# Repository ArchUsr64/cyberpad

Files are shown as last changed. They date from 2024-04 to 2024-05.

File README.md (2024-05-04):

# cyberpad
Macropad in cyberpunk style

## Features
- 16-key matrix layout
- Two rotary encoders (knobs)
- RGB lighting

## Parts Required
| Part | Quantity | Description |
|  - | - |  -  |
| Raspberry Pi Pico | 1 | Microcontroller that powers the whole thing |
| M3 screw | 8 | Used to mount the top and bottom plates together |
| M2 screw | 4 | Used to mount the raspberry pi pico to the top plate |
| M3 standoff | 4 | Provide spacing between the top and bottom plate to house the electronics |
| Switch | 16 | Key switches mounted to the top plate (both 3-pin and 5-pin work)|
| Keycaps | 16 | Keycaps for the switches |
| Diodes | 16 | Required to achieve n-key rollover |
| USB Cable | 1 | Used to connect the pico to the computer |
| RGB LED | 6 | For RGB lighting, firmware expects common anode type |
| Potentiometer | 3 | Used to control the color of RGB lights |
| Type C breakout board (optional) | 1 | Use TP2 and TP3 test points for external USB port |
| Bump Switch (optional) | 1 | Used to get the board to bootloader mode |

## Wiring



The diodes should be connected in `Column to Row` ordering i.e the `cathode` of the diode (the side with the line) should be facing away from the keys and the `cathode` of the diodes in same row should all be connected.  

The `anode` of the diodes should each connect to one pin of the switch and the other pin should be connected straight with all the pins of switches in same column. 
For wiring the Raspberry Pi Pico, the indexing used in the wiring diagram above corresponds to the pico's pinout as follows:

| Row | 0 | 1 | 2 | 3 |
|  -  | - | - | - | - |
| Pin | 5 | 6 | 7 | 8 |

| Column | 0 | 1 | 2 | 3 |
|  -  | - | - | - | - |
| Pin | 20 | 19 | 21 | 22 |

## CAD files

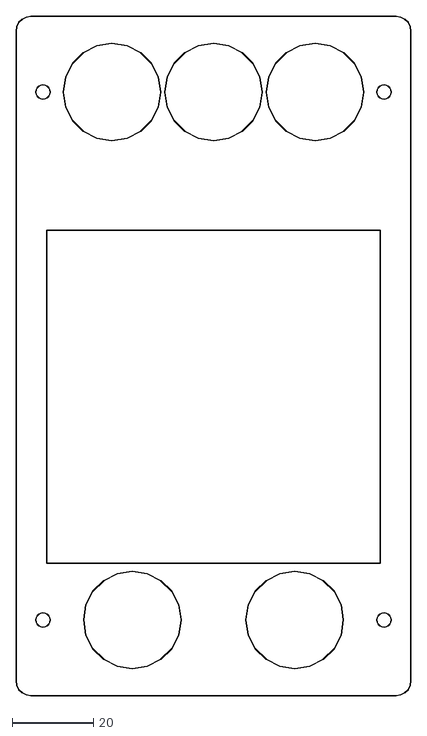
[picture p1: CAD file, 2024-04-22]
cad_files/top_cover.dxf
97.2 x 167.2

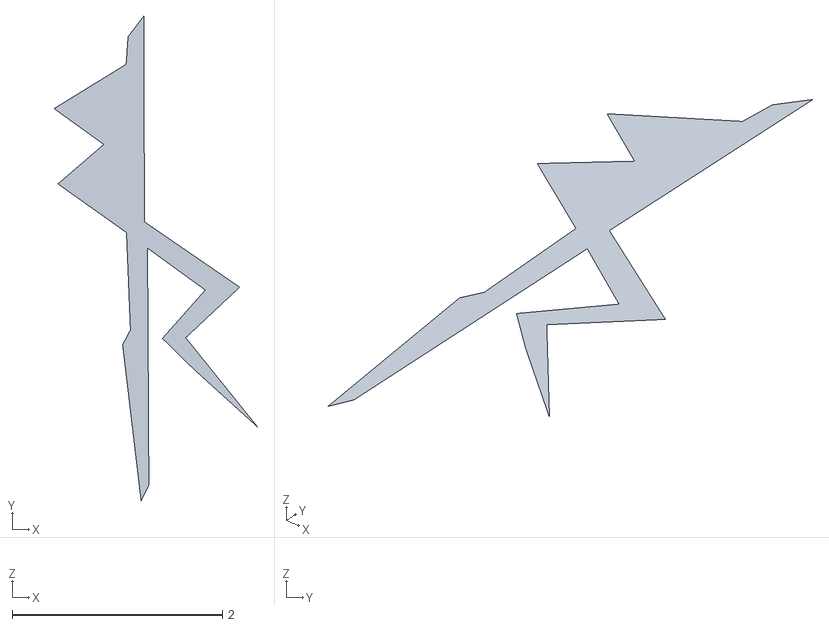
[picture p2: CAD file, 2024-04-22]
edge.stl
1.94 x 4.62 x 0

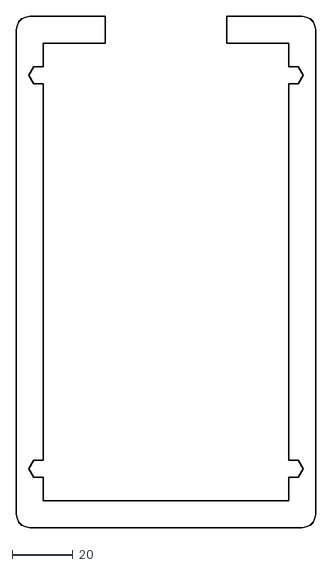
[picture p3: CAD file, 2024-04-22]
cad_files/middle_bottom.dxf
98.8 x 168.8

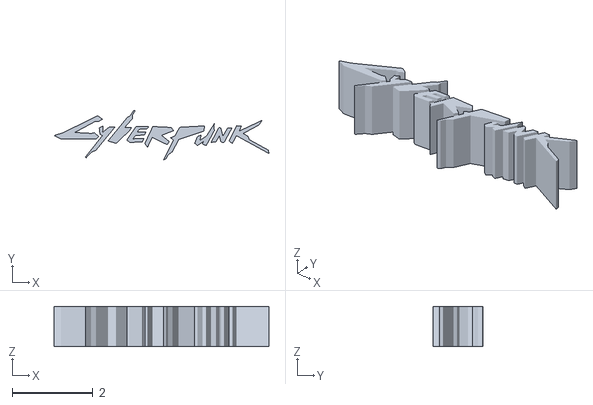
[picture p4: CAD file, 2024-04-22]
cbp.stl
5.32 x 1.23 x 1

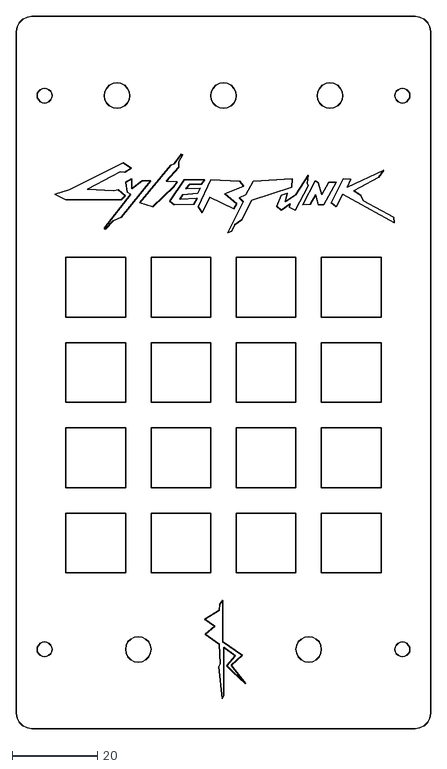
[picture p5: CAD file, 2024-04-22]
cad_files/top.dxf
97.2 x 167.2

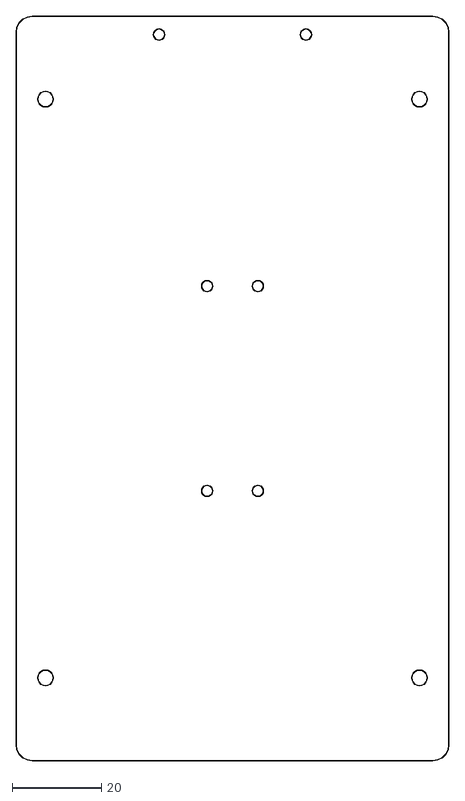
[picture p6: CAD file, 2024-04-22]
cad_files/bottom.dxf
97.2 x 167.2

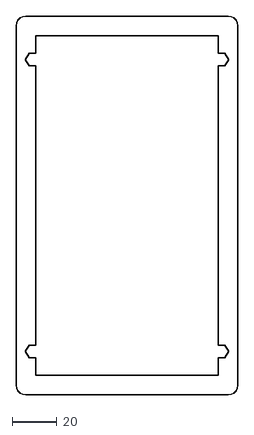
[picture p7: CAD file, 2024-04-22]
cad_files/middle.dxf
98.8 x 168.8

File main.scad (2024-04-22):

$fn = 20;

key_count = 4;
screw_holes = [[42, -55], [42, 75]];
pot_d = 24;
// pot_d = 6;
offset_d = 4;
// key_hole_size= 22;
key_hole_size= 14;
screw_hole_m2 = 2.5;
// screw_hole_m3 = 6.5;
screw_hole_m3 = 3.5;

module base() {
 translate([0, 10, 0]) square([90, 160], center = true);
}

// color([1, 0, 0, 0.5]) middle();
difference() {
	offset(offset_d * 0.9) base();
	top();
}

module top() {
	translate([0, 20 * key_count / 2 + 12, 0]) scale(15) projection() import("cbp.stl");
	translate([-20 * key_count / 2 + 10, -20 * key_count / 2 + 10, 0])
	// Key holes
	union() {
		for(i = [0 : key_count - 1]) {
			for(j = [0 : key_count - 1]) {
				translate([20 * i, 20 * j, 0])
					square(key_hole_size, center = true);
			}
		}
	}
	translate([0, -55, 0]) scale(5) projection() import("edge.stl");
	holes();
	translate([-20, -55, 0]) circle(d = pot_d);
	translate([20, -55, 0]) circle(d = pot_d);
	translate([0, 75, 0]) circle(d = pot_d);
	translate([-25, 75, 0]) circle(d = pot_d);
	translate([25, 75, 0]) circle(d = pot_d);
}

module holes() {
	// Screw holes
	// $fn = 6;
	for(i = [0 : len(screw_holes) - 1]) {
		translate([screw_holes[i][0], screw_holes[i][1], 0]) circle(d = screw_hole_m3);
		translate([-screw_holes[i][0], screw_holes[i][1], 0]) circle(d = screw_hole_m3);
	}
}
module bottom() {
	holes();
	translate([0, 10, 0]) pi_pico();
	translate([0, 90 + offset_d, 0]) type_c_hole();
}
module middle() {
	difference() {
		offset(offset_d * 1.1) base();
		offset(offset_d * -1.1) base();
		// translate([0, 90 + offset_d, 0]) type_c();
		holes();
	}
}
module pi_pico() {
	hole_offset_x = 11.4;
	hole_offset_y = 46;
	holes =
		[[hole_offset_x / 2, hole_offset_y / 2],
		 [hole_offset_x / 2, -hole_offset_y / 2],
		 [-hole_offset_x / 2, hole_offset_y / 2],
		 [-hole_offset_x / 2, -hole_offset_y / 2]];
	for (i = [0:len(holes) - 1]) {
		translate([holes[i][0], holes[i][1], 0]) circle(d = screw_hole_m2);
	}
}
module type_c_hole() {
	x_offset = 33;
	y_offset = 4.5;
	translate([-x_offset / 2, -y_offset, 0])
		circle(d = screw_hole_m2);
	translate([x_offset / 2, -y_offset, 0])
		circle(d = screw_hole_m2);
}
module type_c() {
	y_offset = 4.5;
	translate([0, -y_offset, 0])
		square([40, 10], center = true);
}

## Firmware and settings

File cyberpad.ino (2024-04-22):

#include <Keyboard.h>

#define RED_OUT 16
#define GREEN_OUT 17
#define BLUE_OUT 18

#define RED_IN A0
#define GREEN_IN A1
#define BLUE_IN A2

#define ROTARY_0_SW 12
#define ROTARY_0_DT 13
#define ROTARY_0_CLK 14

#define ROTARY_1_SW 11
#define ROTARY_1_DT 10
#define ROTARY_1_CLK 9

const uint8_t ROW_PINS[4] = {5, 6, 7, 8};
const uint8_t COL_PINS[4] = {20, 19, 21, 22};

const uint8_t KEYMAP[4][4] = {
  {KEY_F13, KEY_F14, KEY_F15, KEY_F16},
  {KEY_F17, KEY_F18, KEY_F19, KEY_F20},
  {KEY_F21, KEY_F22, KEY_F23, KEY_F24},
  {KEY_KP_SLASH, KEY_KP_ASTERISK, KEY_KP_MINUS, KEY_KP_PLUS},
};

const uint8_t ROT_MAP[2][2] = {
  {KEY_DOWN_ARROW, KEY_UP_ARROW},
  {KEY_PAGE_DOWN, KEY_PAGE_UP},
};

const uint8_t ROT_SWITCH_MAP[2] = {KEY_HOME, KEY_END};

uint16_t prev_state = 0;
uint8_t prev_rot_0 = 0;
uint8_t prev_rot_1 = 0;
uint8_t prev_rot_sw_0 = 0;
uint8_t prev_rot_sw_1 = 0;

void setup() {
  Serial.begin(9600);
  Keyboard.begin();

  pinMode(RED_OUT, OUTPUT);
  pinMode(GREEN_OUT, OUTPUT);
  pinMode(BLUE_OUT, OUTPUT);
  pinMode(RED_IN, INPUT);
  pinMode(GREEN_IN, INPUT);
  pinMode(BLUE_IN, INPUT);

  for(int i = 0; i < 4; i++)
    pinMode(COL_PINS[i], OUTPUT);
  for(int i = 0; i < 4; i++)
    pinMode(ROW_PINS[i], INPUT_PULLDOWN);

  pinMode(ROTARY_0_SW, INPUT_PULLUP);
  pinMode(ROTARY_0_DT, INPUT);
  pinMode(ROTARY_0_CLK, INPUT);
  pinMode(ROTARY_1_SW, INPUT_PULLUP);
  pinMode(ROTARY_1_DT, INPUT);
  pinMode(ROTARY_1_CLK, INPUT);

  prev_rot_0 = digitalRead(ROTARY_0_CLK);
  prev_rot_1 = digitalRead(ROTARY_1_CLK);
  prev_rot_sw_0 = digitalRead(ROTARY_0_SW);
  prev_rot_sw_1 = digitalRead(ROTARY_1_SW);
}

void loop() {
  // RGB controls
  uint16_t red_val = map(analogRead(RED_IN), 0, 1024, 0, 270);
  uint16_t green_val = map(analogRead(GREEN_IN), 0, 1024, 0, 270);
  uint16_t blue_val = map(analogRead(BLUE_IN), 0, 1024, 0, 270);
  analogWrite(RED_OUT, red_val);
  analogWrite(GREEN_OUT, green_val);
  analogWrite(BLUE_OUT, blue_val);

  uint16_t state = 0;
  for (int i = 0; i < 4; i++) {
    for (int j = 0; j < 4; j++) {
      digitalWrite(COL_PINS[i], HIGH);
      if (digitalRead(ROW_PINS[j]) == HIGH) {
        state |= 1 << (j * 4 + i);
      }
      digitalWrite(COL_PINS[i], LOW);
    }
  }
  for (int i = 0; i < 4; i++) {
    for (int j = 0; j < 4; j++) {
      unsigned short mask = 1 << (j * 4 + i);
      bool key_state = state & mask;
      bool prev_key_state = prev_state & mask;
      auto keycode = KEYMAP[j][i];
      if (key_state ^ prev_key_state) {
        if (key_state) {
          Keyboard.press(keycode);
        } else {
          Keyboard.release(keycode);
        }
      }
    }
  }
  prev_state = state;

  uint8_t rot_state = digitalRead(ROTARY_0_CLK);
  if (rot_state != prev_rot_0) {
    if (digitalRead(ROTARY_0_DT) != rot_state) {
      Keyboard.write(ROT_MAP[0][0]);
    } else {
      Keyboard.write(ROT_MAP[0][1]);
    }
  }
  prev_rot_0 = rot_state;

  rot_state = digitalRead(ROTARY_1_CLK);
  if (rot_state != prev_rot_1) {
    if (digitalRead(ROTARY_1_DT) != rot_state) {
      Keyboard.write(ROT_MAP[1][0]);
    } else {
      Keyboard.write(ROT_MAP[1][1]);
    }
  }
  prev_rot_1 = rot_state;

  if (digitalRead(ROTARY_0_SW) == LOW && prev_rot_sw_0 == HIGH) {
    Keyboard.press(ROT_SWITCH_MAP[0]);
  } else if (digitalRead(ROTARY_0_SW) == HIGH && prev_rot_sw_0 == LOW) {
    Keyboard.release(ROT_SWITCH_MAP[0]);
  }
  if (digitalRead(ROTARY_1_SW) == LOW && prev_rot_sw_1 == HIGH) {
    Keyboard.press(ROT_SWITCH_MAP[1]);
  } else if (digitalRead(ROTARY_1_SW) == HIGH && prev_rot_sw_1 == LOW) {
    Keyboard.release(ROT_SWITCH_MAP[1]);
  }
  prev_rot_sw_0 = digitalRead(ROTARY_0_SW);
  prev_rot_sw_1 = digitalRead(ROTARY_1_SW);

  delay(10);
  // put your main code here, to run repeatedly:
}

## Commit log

2024-04-22 hw: add hardware files
    [bottom.dxf, cbp.stl, edge.stl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]
2024-04-22 ino: add arduino source
2024-05-04 hw: move to `cad_files`
    [bottom.dxf, middle.dxf, middle_bottom.dxf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]
